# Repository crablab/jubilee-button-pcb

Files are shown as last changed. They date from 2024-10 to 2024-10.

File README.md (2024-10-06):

# jubilee-button-pcb

PCB for the Jubilee Line button replacement PCB. 

Created using KiCad

Check out some sample code here: https://github.com/willfurnell/jubilee-hue

Based on the [original by Will Furnell](https://github.com/willfurnell/jubilee-button-pcb). 

Released under the [MIT Licence](LICENSE). 

You should simply be able to send this off to JLCPCB for manufacture if you wish.

Or, [contact me](mailto:hugh@crablab.uk) as I have some boards already produced.

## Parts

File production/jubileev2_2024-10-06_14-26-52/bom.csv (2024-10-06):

Designator | Footprint | Quantity | Value | LCSC Part #
ANT1 | ESP32WROOM32D | 1 | ESP32-WROOM-32D
C1, C10, C13, C2, C3, C5 | 0805 | 6 | 10uF
C11, C4, C8 | 0805 | 3 | 100nF
C12, C6, C7 | 0805 | 3 | 0.1uF
D1 | 0805 | 1 | POWER_LED
D4 | 0805 | 1 | ESP_LED
D5, D6 | D_SOD-123 | 2 | D_Small
F1 | 1206 | 1 | Polyfuse
H1, H2, H3, H4 | MountingHole_3.5mm_Pad_TopBottom | 4 | MountingHole_Pad
IC2 | SOIC127P600X175-14N | 1 | 74HC14D,653
J3 | SolderWire-0.5sqmm_1x02_P4.6mm_D0.9mm_OD2.1mm | 1 | LED_RING_PADS
Q1 | SOT65P230X110-6N | 1 | UMH3N
Q2 | SOT-23 | 1 | AO3400A
Q3 | SOT-223-3_TabPin2 | 1 | PZT2222A
R1, R12 | 0805 | 2 | 2K
R10 | 0805 | 1 | 5K6
R11 | 0805 | 1 | 50
R2, R8, R9 | 0805 | 3 | 10K
R3, R4 | 0805 | 2 | 5.1K
S2 | FSM2JRT | 1 | RESET
SW3 | SolderWire-0.5sqmm_1x02_P4.6mm_D0.9mm_OD2.1mm | 1 | MAIN_BUTTON
U1 | SOT-223-3_TabPin2 | 1 | AMS1117-3.3
U2 | SOT-223-3_TabPin2 | 1 | AMS1117-5.0
U3 | SOIC-16_3.9x9.9mm_P1.27mm | 1 | CH340C
U4 | TSSOP-16_4.4x5mm_P0.65mm | 1 | IP2721
U5 | TO-252-2 | 1 | 78D09LL-TN3-R
USB1 | HRO-TYPE-C-31-M-12 | 1 | HRO-TYPE-C-31-M-12

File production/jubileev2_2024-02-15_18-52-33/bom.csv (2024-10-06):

Designator | Footprint | Quantity | Value | LCSC Part #
ANT1 | ESP32WROOM32D | 1 | ESP32-WROOM-32D
C1, C10, C2, C3, C5 | 0805 | 5 | 10uF
C11, C4, C8 | 0805 | 3 | 100nF
C12, C6 | 0805 | 2 | 0.1uF
D1 | 0805 | 1 | POWER_LED
D2 | D_SOD-123 | 1 | D_Schottky
D3 | D_SOD-123 | 1 | D
D4 | 0805 | 1 | ESP_LED
D5 | D_SOD-123 | 1 | D_Small
F1 | 1206 | 1 | Polyfuse
IC2 | SOIC127P600X175-14N | 1 | 74HC14D,653
J1 | Barrel_Jack_5.5mmODx2.1mmID_PJ-202A | 1 | PJ-202A
Q1 | SOT65P230X110-6N | 1 | UMH3N
Q3 | SOT-223-3_TabPin2 | 1 | PZT2222A
R1, R12 | 0805 | 2 | 2K
R10 | 0805 | 1 | 5K6
R11 | 0805 | 1 | 50
R2, R8, R9 | 0805 | 3 | 10K
R3, R4 | 0805 | 2 | 5.1K
S2 | FSM2JRT | 1 | RESET
U1 | SOT-223-3_TabPin2 | 1 | AMS1117-3.3
U2 | SOT-223-3_TabPin2 | 1 | AMS1117-5.0
U3 | SOIC-16_3.9x9.9mm_P1.27mm | 1 | CH340C
USB1 | HRO-TYPE-C-31-M-12 | 1 | HRO-TYPE-C-31-M-12

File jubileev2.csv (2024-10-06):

Id | Designator | Footprint | Quantity | Designation | Supplier and ref
1 | C1,C2,C3,C5,C10,C13 | C_0805_2012Metric | 6 | 10uF
2 | C12,C6,C7 | C_0805_2012Metric | 3 | 0.1uF
3 | D1 | LED_0805_2012Metric | 1 | POWER_LED
4 | D4 | LED_0805_2012Metric | 1 | ESP_LED
5 | F1 | Fuse_1206_3216Metric | 1 | Polyfuse
6 | J3 | SolderWire-0.5sqmm_1x02_P4.6mm_D0.9mm_OD2.1mm | 1 | LED_RING_PADS
7 | Q3 | SOT-223-3_TabPin2 | 1 | PZT2222A
8 | R1,R12 | R_0805_2012Metric | 2 | 2K
9 | R8,R9,R2 | R_0805_2012Metric | 3 | 10K
10 | R10 | R_0805_2012Metric | 1 | 5K6
11 | R11 | R_0805_2012Metric | 1 | 50
12 | SW3 | SolderWire-0.5sqmm_1x02_P4.6mm_D0.9mm_OD2.1mm | 1 | MAIN_BUTTON
13 | U1 | SOT-223-3_TabPin2 | 1 | AMS1117-3.3
14 | U2 | SOT-223-3_TabPin2 | 1 | AMS1117-5.0
15 | H1,H2,H3,H4 | MountingHole_3.5mm_Pad_TopBottom | 4 | MountingHole_Pad
16 | D5,D6 | D_SOD-123 | 2 | D_Small
17 | C8,C4,C11 | C_0805_2012Metric | 3 | 100nF
18 | S2 | FSM2JRT | 1 | RESET
19 | IC2 | SOIC127P600X175-14N | 1 | 74HC14D,653
20 | ANT1 | ESP32WROOM32D | 1 | ESP32-WROOM-32D
21 | Q1 | SOT65P230X110-6N | 1 | UMH3N
22 | R3,R4 | R_0805_2012Metric | 2 | 5.1K
23 | USB1 | HRO-TYPE-C-31-M-12 | 1 | HRO-TYPE-C-31-M-12
24 | U3 | SOIC-16_3.9x9.9mm_P1.27mm | 1 | CH340C
25 | Q2 | SOT-23 | 1 | AO3400A
26 | U5 | TO-252-2 | 1 | 78D09LL-TN3-R
27 | U4 | TSSOP-16_4.4x5mm_P0.65mm | 1 | IP2721

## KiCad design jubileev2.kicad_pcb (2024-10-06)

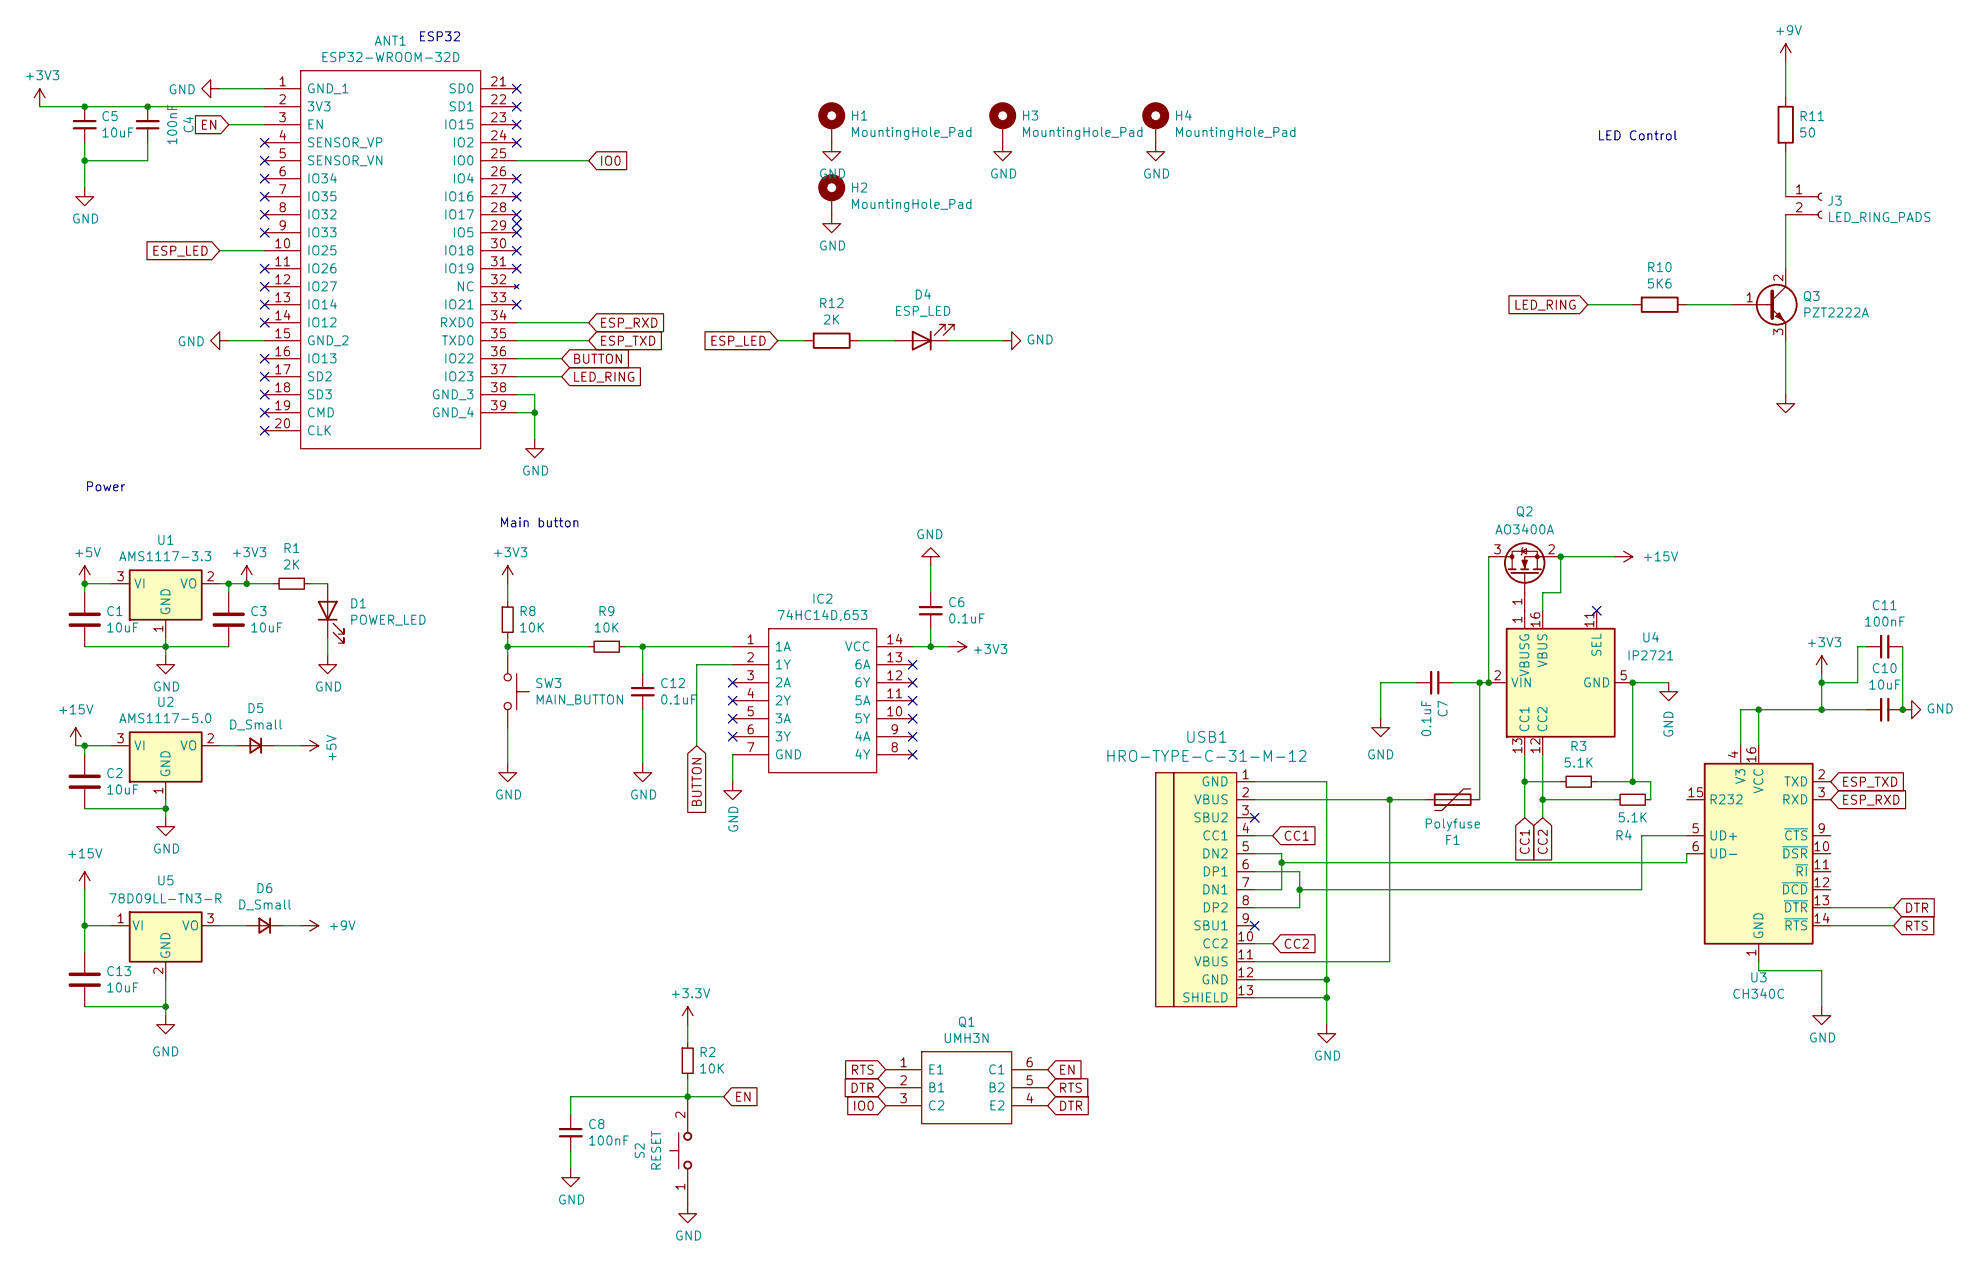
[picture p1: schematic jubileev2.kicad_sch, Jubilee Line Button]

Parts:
ANT1: ESP32-WROOM-32D; ESP32WROOM32D; Manufacturer_Part_Number ESP32-WROOM-32D; Mouser Part Number N/A
C1, C2, C3, C5, C10, C13: 10uF; C_0805_2012Metric
C4, C8, C11: 100nF; C_0805_2012Metric
C6, C7, C12: 0.1uF; C_0805_2012Metric
D1: POWER_LED; LED_0805_2012Metric
D4: ESP_LED; LED_0805_2012Metric
D5, D6: D_Small; D_SOD-123
F1: Polyfuse; Fuse_1206_3216Metric
H1, H2, H3, H4: MountingHole_Pad; MountingHole_3.5mm_Pad_TopBottom
IC2: 74HC14D,653; SOIC127P600X175-14N; Manufacturer_Part_Number 74HC14D,653; Mouser Part Number 771-74HC14D-T
J3: LED_RING_PADS; SolderWire-0.5sqmm_1x02_P4.6mm_D0.9mm_OD2.1mm
Q1: UMH3N; SOT65P230X110-6N; Manufacturer_Part_Number UMH3N
Q2: AO3400A; SOT-23
Q3: PZT2222A; SOT-223-3_TabPin2
R1, R12: 2K; R_0805_2012Metric
R2, R8, R9: 10K; R_0805_2012Metric
R3, R4: 5.1K; R_0805_2012Metric
R10: 5K6; R_0805_2012Metric
R11: 50; R_0805_2012Metric
S2: RESET; FSM2JRT; Mouser Part Number 506-FSM2JRT
SW3: MAIN_BUTTON; SolderWire-0.5sqmm_1x02_P4.6mm_D0.9mm_OD2.1mm
U1: AMS1117-3.3; SOT-223-3_TabPin2
U2: AMS1117-5.0; SOT-223-3_TabPin2
U3: CH340C; SOIC-16_3.9x9.9mm_P1.27mm
U4: IP2721; TSSOP-16_4.4x5mm_P0.65mm
U5: 78D09LL-TN3-R; TO-252-2
USB1: HRO-TYPE-C-31-M-12

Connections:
+5V: C1.1, D5.1 (K), U1.3 (VI)
+9V: D6.1 (K), R11.1
+15V: C2.1, C13.1, Q2.2 (S), U2.3 (VI), U4.16 (VBUS), U5.1 (VI)
BUTTON: ANT1.36 (IO22), IC2.2 (1Y)
CC1: R3.2, U4.13 (CC1), USB1.4 (CC1)
CC2: R4.2, U4.12 (CC2), USB1.10 (CC2)
DTR: Q1.2 (B1), Q1.4 (E2), U3.13 (~DTR)
EN: ANT1.3 (EN), C8.1, Q1.6 (C1), R2.2, S2.2
ESP_LED: ANT1.10 (IO25), R12.2
ESP_RXD: ANT1.34 (RXD0), U3.3 (RXD)
ESP_TXD: ANT1.35 (TXD0), U3.2 (TXD)
GND: ANT1.1 (GND_1), ANT1.15 (GND_2), ANT1.38 (GND_3), ANT1.39 (GND_4), C1.2, C2.2, C3.2, C4.1, C5.2, C6.1, C7.2, C8.2, C10.1, C11.2, C12.2, C13.2, D1.1 (K), D4.1 (K), H1.1, H2.1, H3.1, H4.1, IC2.7 (GND), Q3.3 (E), R3.1, R4.1, S2.1, SW3.2, U1.1 (GND), U2.1 (GND), U3.1 (GND), U4.5 (GND), U5.2 (GND), USB1.1 (GND), USB1.12 (GND), USB1.13 (SHIELD)
IO0: ANT1.25 (IO0), Q1.3 (C2)
LED_RING: ANT1.37 (IO23), R10.2
unnamed: D1.2 (A), R1.1
unnamed: D4.2 (A), R12.1
unnamed: D5.2 (A), U2.2 (VO)
unnamed: D6.2 (A), U5.3 (VO)
unnamed: F1.1, USB1.2 (VBUS), USB1.11 (VBUS)
unnamed: C12.1, IC2.1 (1A), R9.1
unnamed: J3.1, R11.2
unnamed: J3.2, Q3.2 (C)
unnamed: C7.1, F1.2, Q2.3 (D), U4.2 (VIN)
unnamed: Q2.1 (G), U4.1 (VBUSG)
unnamed: Q3.1 (B), R10.1
unnamed: R8.2, R9.2, SW3.1
unnamed: U3.5 (UD+), USB1.6 (DP1), USB1.8 (DP2)
unnamed: U3.6 (UD-), USB1.5 (DN2), USB1.7 (DN1)
RTS: Q1.1 (E1), Q1.5 (B2), U3.14 (~RTS)

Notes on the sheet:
Main button
ESP32
Power
LED Control

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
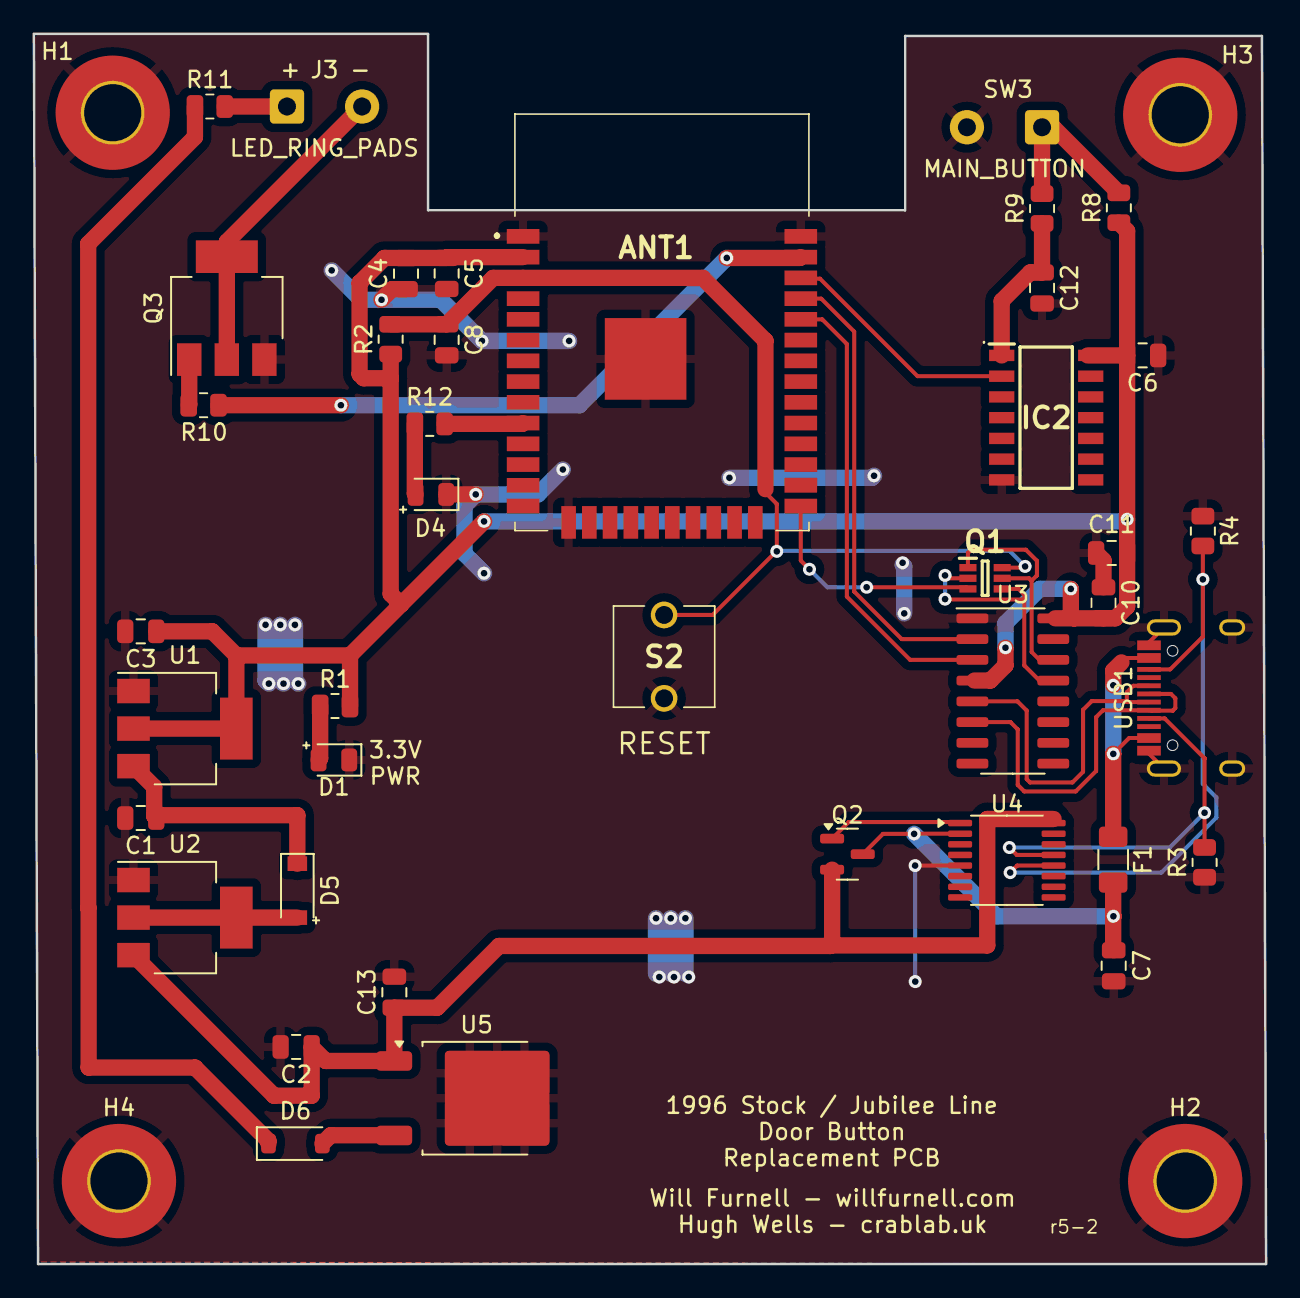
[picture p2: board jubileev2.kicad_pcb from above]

Board: 2 copper layers, 75.4 x 75.3 mm, 44 parts (0 on the bottom side), 30 nets.

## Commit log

2024-10-06 Update PCB with new USB-C PD power supply
    [bom.csv, designators.csv, jubileev2-bom.csv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]
2024-10-06 Remove files from previous iterations
    [jubileev2-bom2.ods, jubileev2.sch, jubileev3-newbom.ods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]
2024-10-06 Update fabrication outputs
    [bom.csv, designators.csv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]
